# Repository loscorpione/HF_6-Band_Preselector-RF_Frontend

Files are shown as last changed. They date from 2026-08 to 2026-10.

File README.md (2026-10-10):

<h2 align="center">HF 6-Band Preselector – RF Frontend</h4>

This project is a 6-band HF RF preselector designed to improve the selectivity and dynamic performance of HF receivers, particularly homebrew and direct-conversion receivers.

<p align="center">
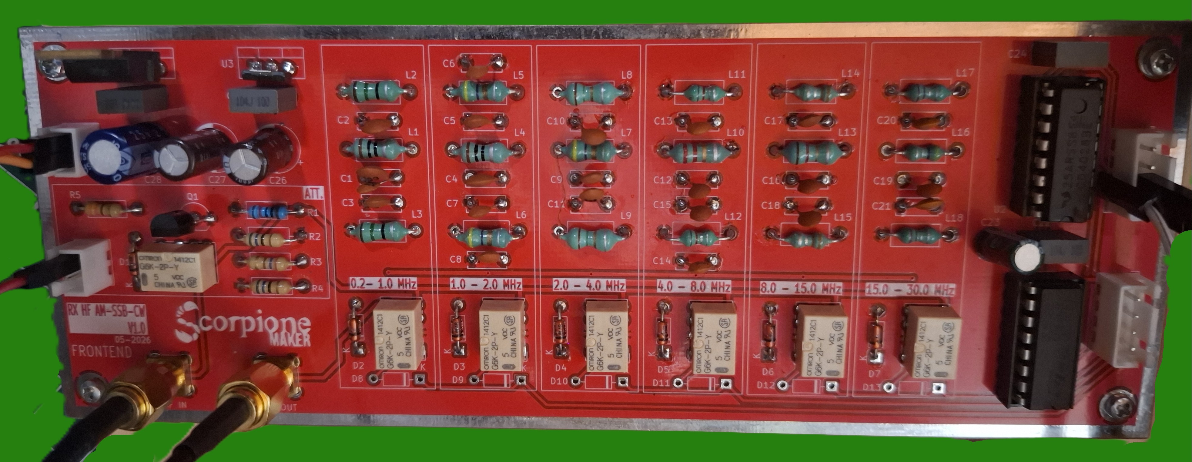
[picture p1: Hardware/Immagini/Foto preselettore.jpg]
  
</p>

The preselector covers the frequency range from 200 kHz to 30 MHz through six LC band-pass filters. The appropriate filter is selected automatically according to the band selected on the VFO.
The project was developed as an RF frontend for my ESP32 + Si5351 VFO/BFO, creating an integrated and automatically controlled RF signal chain.
In addition to the band-pass filters, the board includes a selectable 0 / -20 dB RF attenuator, controlled directly by the VFO.

<h2 align="center">🎬 Video del progetto</h2>

<p align="center">
  <a href="https://youtu.be/hL2VTXRHFpw">
    
  </a>
</p>

<h2 align="center">📻 Frequency coverage</h2>
Filter	Frequency range	Main applications
1	0.2 – 1 MHz	Long Wave, Medium Wave, 630 m
2	1 – 2 MHz	Medium Wave, 160 m
3	2 – 4 MHz	80 m, 60 m
4	4 – 8 MHz	40 m, Short Wave
5	8 – 15 MHz	30 m, 20 m, Short Wave
6	15 – 30 MHz	17 m, 15 m, 12 m, 10 m, Short Wave

<h2 align="center">🔛Filter Switching</h2>

The six filters are selected using RF relays controlled by a CD4028 decoder and an ULN2003 Darlington transistor array.
The VFO sends the selected band information to the CD4028, which activates the corresponding output. The ULN2003 then drives the relay coil, allowing the correct RF filter to be connected.
This approach reduces the number of control lines required between the VFO and the RF frontend while keeping the RF switching section simple and reliable.

## Integrazione con il VFO/BFO

- [Mappatura delle uscite digitali per la selezione dei filtri](Mappatura-Uscite-Band.md)
- [Repository VFO/BFO HF ESP32 + Si5351](https://github.com/loscorpione/VFO-BFO-HF-ESP32-Si5351)

<h2 align="center">📻 RF Attenuator</h2>

The board also includes a selectable 0 / -20 dB attenuator based on a 50 Ω resistive network.
The attenuator can be controlled directly from the VFO and can be useful when the receiver is overloaded by strong signals or out-of-band energy.

<h2 align="center">🔌 Testing</h2>

The filters were tested using a NanoVNA, measuring their frequency response, insertion loss and bandwidth.
The measured responses do not perfectly match the calculated values. The differences are most likely related to component tolerances, particularly the inductors.
Further adjustments to the filter component values are therefore planned to improve the correspondence between the calculated and measured responses.

<h2 align="center">🛠️ Hardware</h2>

The PCB was designed with particular attention to RF layout:

short RF tracks;
extensive ground plane;
physically separated filter sections;
relays positioned close to the RF paths;
50 Ω RF input and output;
dedicated filtering for each frequency range.
Status

Working prototype – further RF optimization planned.

<h2 align="center"></h2>

This repository contains the hardware design files, documentation and test information for the project.

<h2 align="center">⚠️ Disclaimer</h2>

This project is intended for educational, experimental and amateur-radio purposes.
RF circuits can behave differently depending on component tolerances, PCB construction, wiring, grounding and measurement equipment.
Always verify the circuit and its behavior before connecting it to valuable radio equipment.

<h2 align="center">📄 License</h2>

The licensing terms for this project are currently being finalized.
The original filter design is based on the work of Dian Kurniawan, which in turn references the work of Matti Hohtola (OH7SV).
Commercial use or commercial redistribution of this implementation is not authorized while the final licensing terms are being established.

ScorpioneMaker

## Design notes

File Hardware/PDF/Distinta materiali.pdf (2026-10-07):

Reference | Qty Value | Footprint | Datasheet
C1 | 1 10+2.2 nF | Capacitor_THT:C_Disc_D6.0mm_W2.5mm_P5.00mm | ~
C2 | 1 10nF | Capacitor_THT:C_Disc_D6.0mm_W2.5mm_P5.00mm | ~
C3 | 1 6.8nF | Capacitor_THT:C_Disc_D6.0mm_W2.5mm_P5.00mm | ~
C4 | 1 1nF+220pF | Capacitor_THT:C_Disc_D6.0mm_W2.5mm_P5.00mm | ~
C5,C6,C7,C8 | 4 1.5nF | Capacitor_THT:C_Disc_D6.0mm_W2.5mm_P5.00mm | ~
C9,C17,C18 | 3 680pF | Capacitor_THT:C_Disc_D6.0mm_W2.5mm_P5.00mm | ~
C10,C11 | 2 2nF | Capacitor_THT:C_Disc_D6.0mm_W2.5mm_P5.00mm | ~
C12,C15,C16 | 3 180pF | Capacitor_THT:C_Disc_D6.0mm_W2.5mm_P5.00mm | ~
C13,C14 | 2 1nF | Capacitor_THT:C_Disc_D6.0mm_W2.5mm_P5.00mm | ~
C19 | 1 120pF | Capacitor_THT:C_Disc_D6.0mm_W2.5mm_P5.00mm | ~
C20,C21 | 2 270pF | Capacitor_THT:C_Disc_D6.0mm_W2.5mm_P5.00mm | ~
C22,C24,C25,C29 | 4 100nF | Capacitor_THT:C_Rect_L7.0mm_W2.5mm_P5.00mm | ~
C23 | 1 10uF16V | Capacitor_THT:CP_Radial_D4.0mm_P2.00mm | ~
C26 | 1 100uF 25V | Capacitor_THT:CP_Radial_D7.5mm_P2.50mm | ~
C27,C28 | 2 100uF25V | Capacitor_THT:CP_Radial_D7.5mm_P2.50mm | ~
D1,D2,D3,D4,D5,D6,D7,D8,D9,D10,
D11,D12,D13 | 13 1N4148 | Diode_THT:D_DO-35_SOD27_P7.62mm_Horizontal | https://assets.nexperia.com/documents/data-sheet/1N4148_1N4448.pdf
H1,H2,H3,H4 | 4 MountingHole_PadMountingHole:MountingHole_3.2mm_M3_DIN965_Pad | ~
J1 | 1 RF OUT | Connector_Coaxial:SMA_Amphenol_901-144_Vertical | ~
J2 | 1 RF IN | Connector_Coaxial:SMA_Amphenol_901-144_Vertical | ~
J3 | 1 +12V | Connector_JST:JST_XH_B2B-XH-A_1x02_P2.50mm_Vertical | ~
J4 | 1 Band | Connector_JST:JST_XH_B4B-XH-A_1x04_P2.50mm_Vertical | ~
J5 | 1 Att. | Connector_JST:JST_XH_B2B-XH-A_1x02_P2.50mm_Vertical | ~
J6 | 1 PBF VFO | Connector_JST:JST_XH_B4B-XH-A_1x04_P2.50mm_Vertical | ~
K1,K2,K3,K4,K5,K6,K7 | 7 G6K-2 | Relay_THT:Relay_DPDT_Omron_G6K-2P-Y | http://omronfs.omron.com/en_US/ecb/products/pdf/en-g6k.pdf
L1,L4 | 2 10uH | Inductor_THT:L_Axial_L7.0mm_D3.3mm_P10.16mm_Horizontal_Fastron_MICC ~
L2,L3 | 2 15uH | Inductor_THT:L_Axial_L7.0mm_D3.3mm_P10.16mm_Horizontal_Fastron_MICC ~
L5,L6,L7 | 3 4.7uH | Inductor_THT:L_Axial_L7.0mm_D3.3mm_P10.16mm_Horizontal_Fastron_MICC ~
L8,L9 | 2 1.5uH | Inductor_THT:L_Axial_L7.0mm_D3.3mm_P10.16mm_Horizontal_Fastron_MICC ~
L10 | 1 2.2uH | Inductor_THT:L_Axial_L7.0mm_D3.3mm_P10.16mm_Horizontal_Fastron_MICC ~
L11,L12 | 2 820nH | Inductor_THT:L_Axial_L7.0mm_D3.3mm_P10.16mm_Horizontal_Fastron_MICC ~
L13 | 1 1.2u | Inductor_THT:L_Axial_L7.0mm_D3.3mm_P10.16mm_Horizontal_Fastron_MICC ~
L14,L15 | 2 330nH | Inductor_THT:L_Axial_L7.0mm_D3.3mm_P10.16mm_Horizontal_Fastron_MICC ~
L16 | 1 470nH | Inductor_THT:L_Axial_L7.0mm_D3.3mm_P10.16mm_Horizontal_Fastron_MICC ~
L17,L18 | 2 220nH | Inductor_THT:L_Axial_L7.0mm_D3.3mm_P10.16mm_Horizontal_Fastron_MICC ~
Q1 | 1 BC547 | Package_TO_SOT_THT:TO-92_Inline_Wide | https://www.onsemi.com/pub/Collateral/BC550-D.pdf
R1 | 1 10k | Resistor_THT:R_Axial_DIN0207_L6.3mm_D2.5mm_P10.16mm_Horizontal~
R2,R4 | 2 56 | Resistor_THT:R_Axial_DIN0207_L6.3mm_D2.5mm_P10.16mm_Horizontal~
R3 | 1 270 | Resistor_THT:R_Axial_DIN0207_L6.3mm_D2.5mm_P10.16mm_Horizontal~
R5 | 1 1K | Resistor_THT:R_Axial_DIN0207_L6.3mm_D2.5mm_P10.16mm_Horizontal~
U1 | 1 ULN2003 | Package_DIP:DIP-16_W7.62mm | http://www.ti.com/lit/ds/symlink/uln2003a.pdf
U2 | 1 4028 | Package_DIP:DIP-16_W7.62mm | http://www.intersil.com/content/dam/Intersil/documents/cd40/cd4028bms.pdf
U3 | 1 LM1117T-3.3 | Package_TO_SOT_THT:TO-220-3_Vertical | http://www.ti.com/lit/ds/symlink/lm1117.pdf
U4 | 1 LM7805_TO220 | Package_TO_SOT_THT:TO-220-3_Vertical | https://www.onsemi.cn/PowerSolutions/document/MC7800-D.PDF

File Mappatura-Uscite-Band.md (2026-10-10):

# Configurazione delle uscite digitali per la selezione dei filtri

## Introduzione

Se si utilizza il preselettore **HF 6-Band Preselector RF Frontend** insieme al progetto [VFO/BFO HF ESP32 + Si5351](https://github.com/loscorpione/VFO-BFO-HF-ESP32-Si5351), è necessario configurare la mappatura delle uscite digitali in funzione della frequenza selezionata sul VFO.

Il firmware del VFO deve generare il codice binario corrispondente alla banda di frequenza utilizzata, in modo da comandare il circuito di selezione dei filtri del preselettore.

## Dove modificare il firmware

La configurazione si trova nel file `DigiOUT.cpp`, all'interno della funzione:

```cpp
void updateModeOutputs()
```

In questa funzione viene verificato il valore di `displayedFrequency` e vengono impostate le uscite digitali in base alla banda di frequenza selezionata.

Per ogni filtro vengono definiti un limite inferiore e un limite superiore. Quando la frequenza rientra nell'intervallo specificato, alla variabile `outputState` viene assegnato il codice binario corrispondente.

**Attenzione:** gli intervalli di frequenza riportati nel codice devono corrispondere alle bande effettive dei filtri installati nel preselettore.

## Tabella di selezione dei filtri

La configurazione di esempio prevede sei filtri passa-banda e una condizione aggiuntiva per le frequenze fuori banda.

| Frequenza selezionata | Codice binario | Banda |
|---|---|---|
| 200 kHz – 1 MHz | `000` | Filtro 1 |
| 1 – 2 MHz | `001` | Filtro 2 |
| 2 – 4 MHz | `010` | Filtro 3 |
| 4 – 8 MHz | `011` | Filtro 4 |
| 8 – 15 MHz | `100` | Filtro 5 |
| 15 – 30 MHz | `101` | Filtro 6 |
| Fuori banda | `110` | Nessun filtro attivo |

I codici binari sono quelli impostati nel firmware e devono essere compatibili con il circuito digitale di decodifica del preselettore.

## Esempio di configurazione nel codice

Il seguente frammento mostra come vengono associate le frequenze ai codici binari:

```cpp
void updateModeOutputs() {
    uint8_t outputState = 0;

    // ====================================================
    // Mappatura: Selezione filtri passa banda Preselettore
    // ====================================================
    if (displayedFrequency >= 200000 &&
        displayedFrequency < 1000000) {
        outputState = 0b000;   // da 200kHz a 1000kHz - Band=000 
    }
    else if (displayedFrequency >= 1000000 &&
             displayedFrequency < 2000000) {
        outputState = 0b001; // 1000kHz a 2000kHz - Band=001
    }
    else if (displayedFrequency >= 2000000 &&
             displayedFrequency < 4000000) {
        outputState = 0b010; // 2000kHz a 4000kHz - Band=010 
    }
    else if (displayedFrequency >= 4000000 &&
             displayedFrequency < 8000000) {
        outputState = 0b011; // 4000kHz a 8000kHz - Band=011
    }
    else if (displayedFrequency >= 8000000 &&
             displayedFrequency < 15000000) {
        outputState = 0b100; // 8000kHz a 15MHz - Band=100
    }
    else if (displayedFrequency >= 15000000 &&
             displayedFrequency <= 30000000) {
        outputState = 0b101;  // 15MHz a 30MHz - Band=101
    }
    else {
        outputState = 0b110;  // Fuori banda - band=110 (nessun filtro attivo)
    }

    // La gestione delle uscite digitali prosegue qui.
}
```

*Nota: questo è un esempio della logica di mappatura. Per mantenere il funzionamento del firmware originale, conservare anche le istruzioni successive della funzione che trasferiscono `outputState` alle uscite fisiche.*

## Come personalizzare la mappatura

Se si utilizzano filtri con intervalli di frequenza differenti, è possibile modificare i limiti delle condizioni `if` e `else if`.

Per ogni filtro occorre:

1. Impostare la frequenza minima di attivazione.
2. Impostare la frequenza massima di attivazione.
3. Assegnare il codice binario previsto dal circuito di decodifica.
4. Verificare che gli intervalli non si sovrappongano e che non rimangano intervalli indesiderati.
5. Verificare il corretto funzionamento delle uscite digitali e dei relè.

Gli estremi degli intervalli devono essere scelti con attenzione per evitare ambiguità nei punti di passaggio tra una banda e la successiva.

## Verifica del funzionamento

Dopo aver modificato e caricato il firmware:

- Selezionare frequenze appartenenti a ciascuna delle sei bande.
- Verificare che il codice binario generato sia quello previsto.
- Controllare che venga attivato il filtro corrispondente.
- Provare anche frequenze inferiori a 200 kHz e superiori a 30 MHz per verificare la condizione fuori banda.

Per maggiori informazioni sul circuito RF e sul relativo sistema di selezione, consultare il [repository HF 6-Band Preselector RF Frontend](https://github.com/loscorpione/HF-6-Band_Preselector-RF_Frontend).

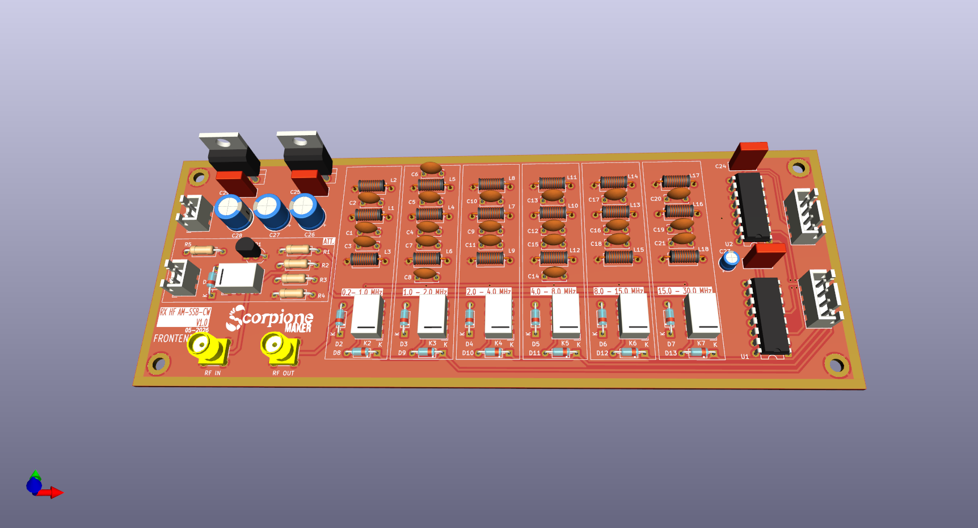
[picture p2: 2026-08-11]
Hardware/Immagini/6x-BPF-FRONTEND.png

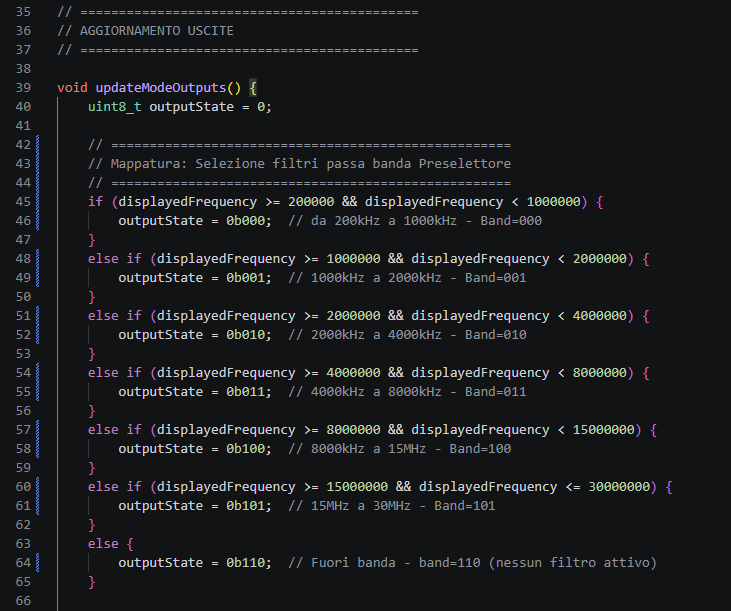
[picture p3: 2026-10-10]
Immage/Mappatura-uscite-band.png

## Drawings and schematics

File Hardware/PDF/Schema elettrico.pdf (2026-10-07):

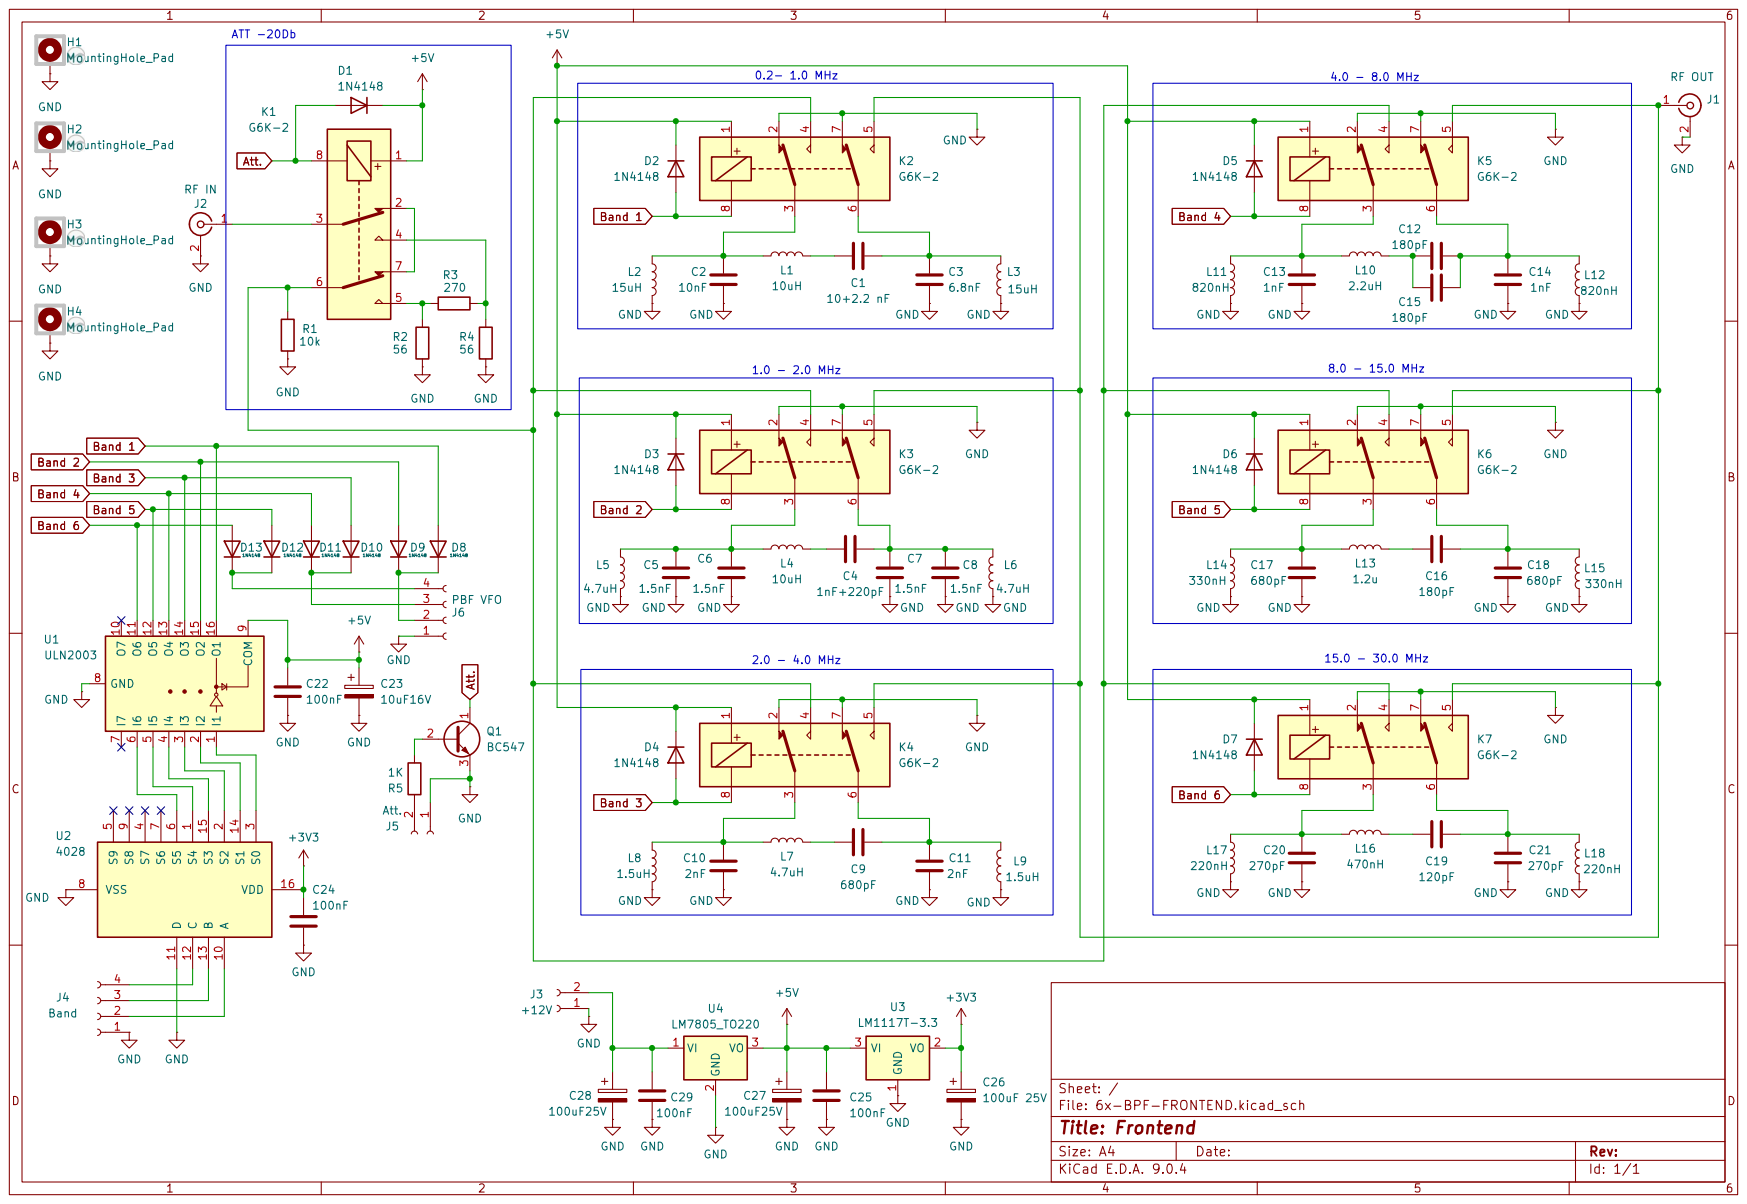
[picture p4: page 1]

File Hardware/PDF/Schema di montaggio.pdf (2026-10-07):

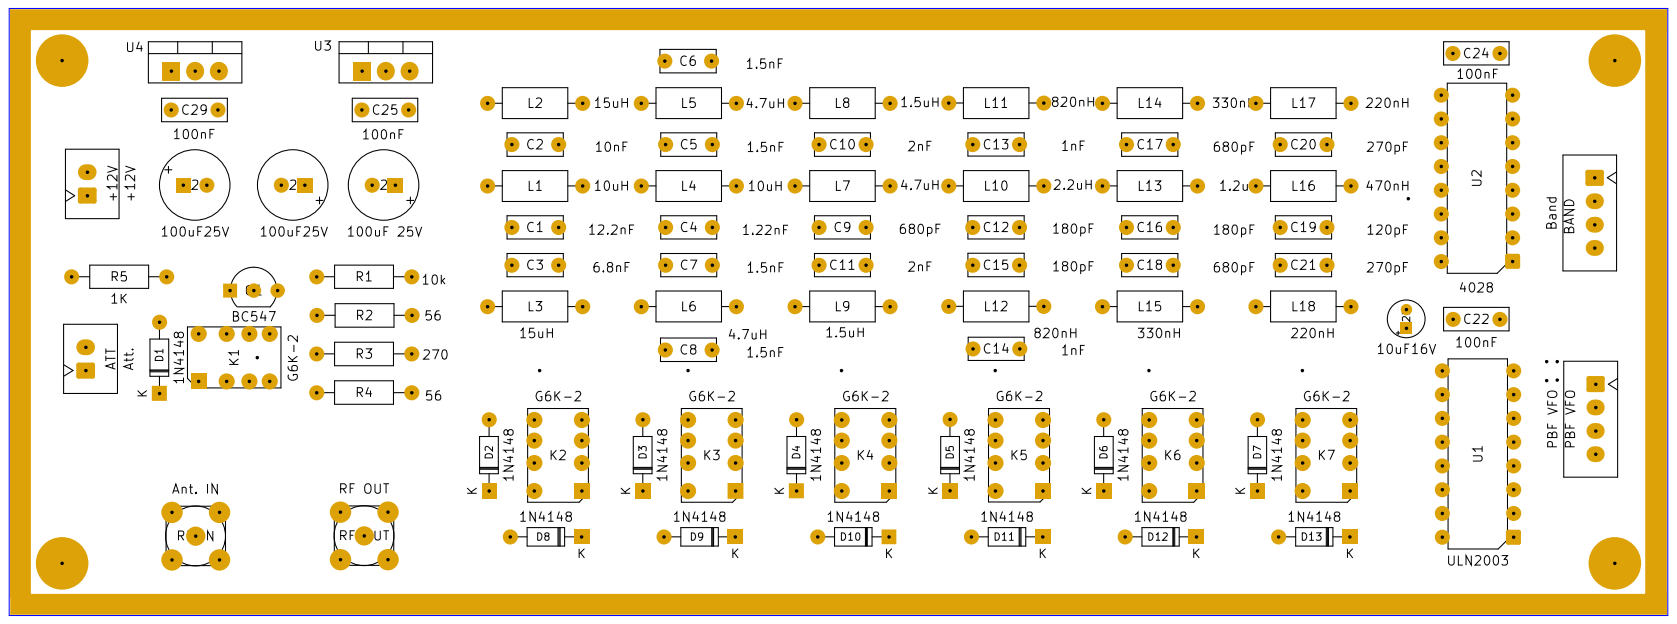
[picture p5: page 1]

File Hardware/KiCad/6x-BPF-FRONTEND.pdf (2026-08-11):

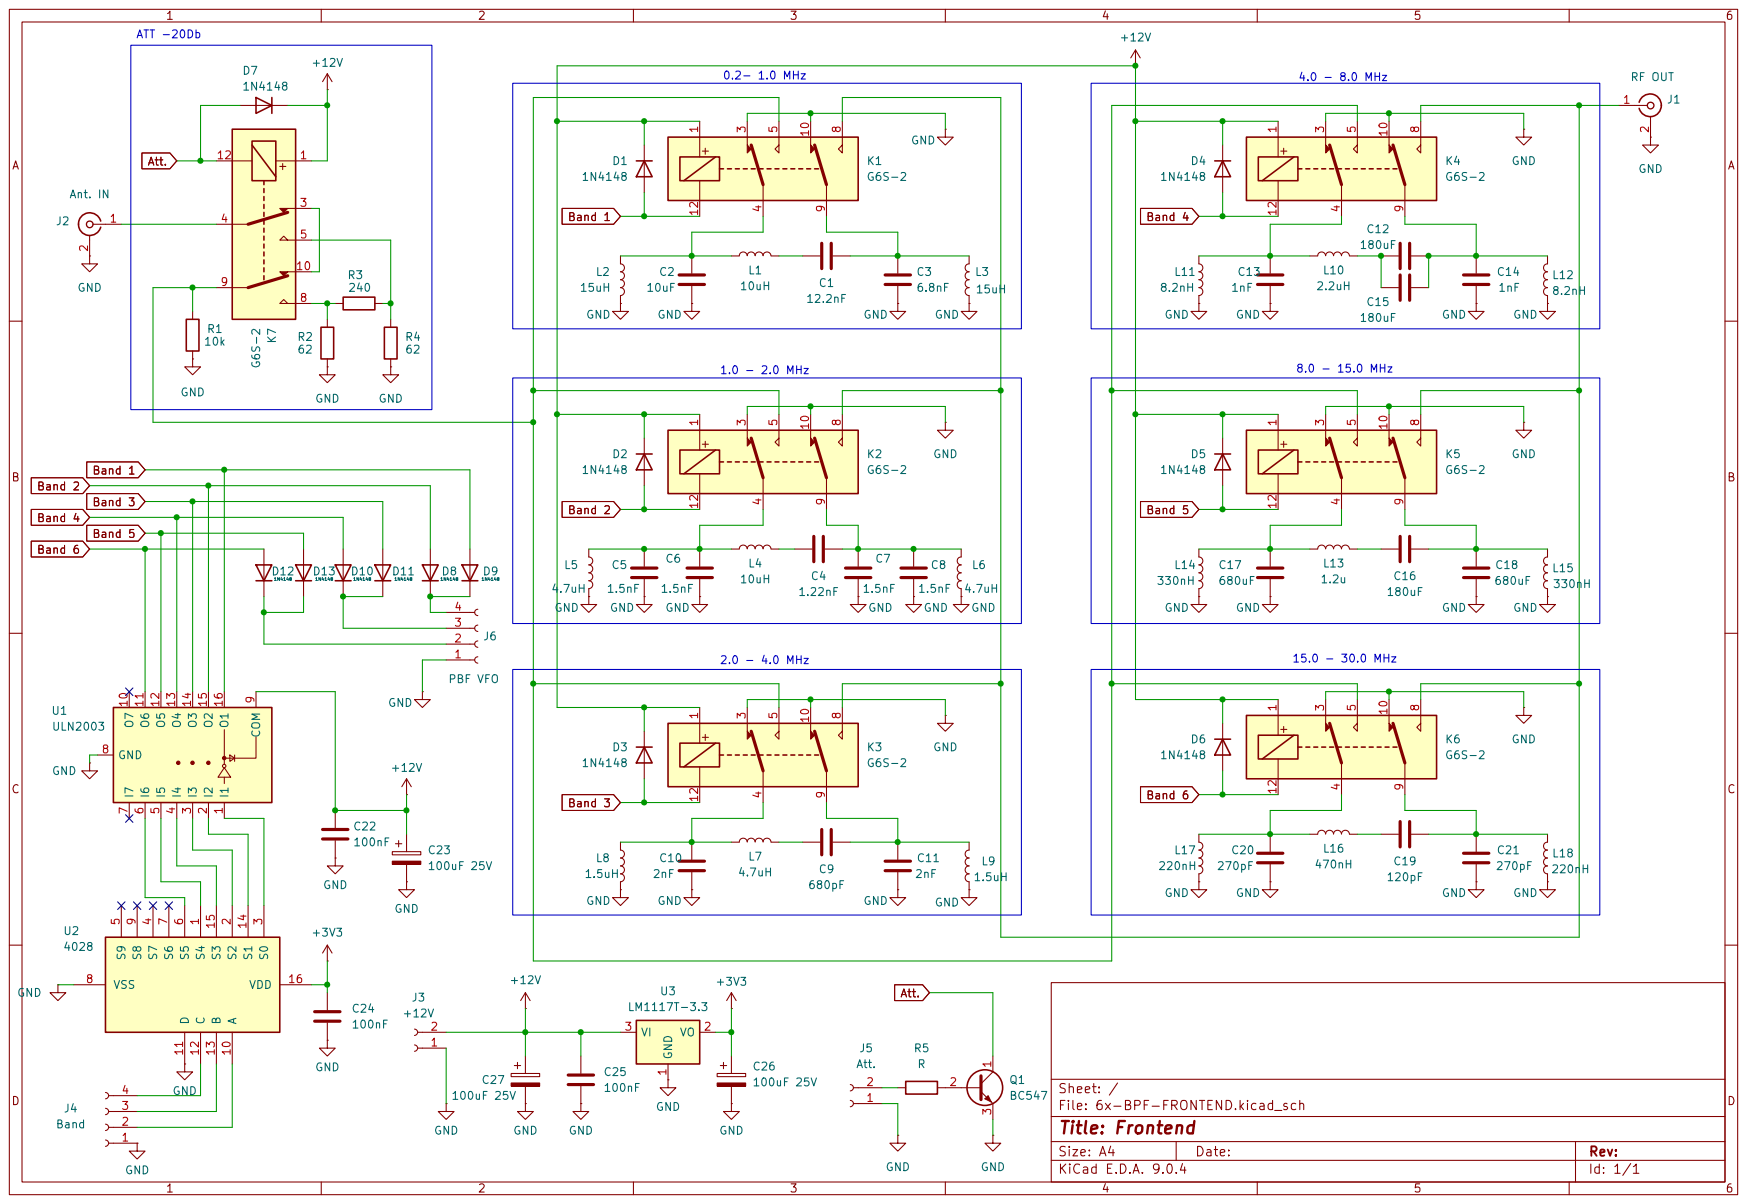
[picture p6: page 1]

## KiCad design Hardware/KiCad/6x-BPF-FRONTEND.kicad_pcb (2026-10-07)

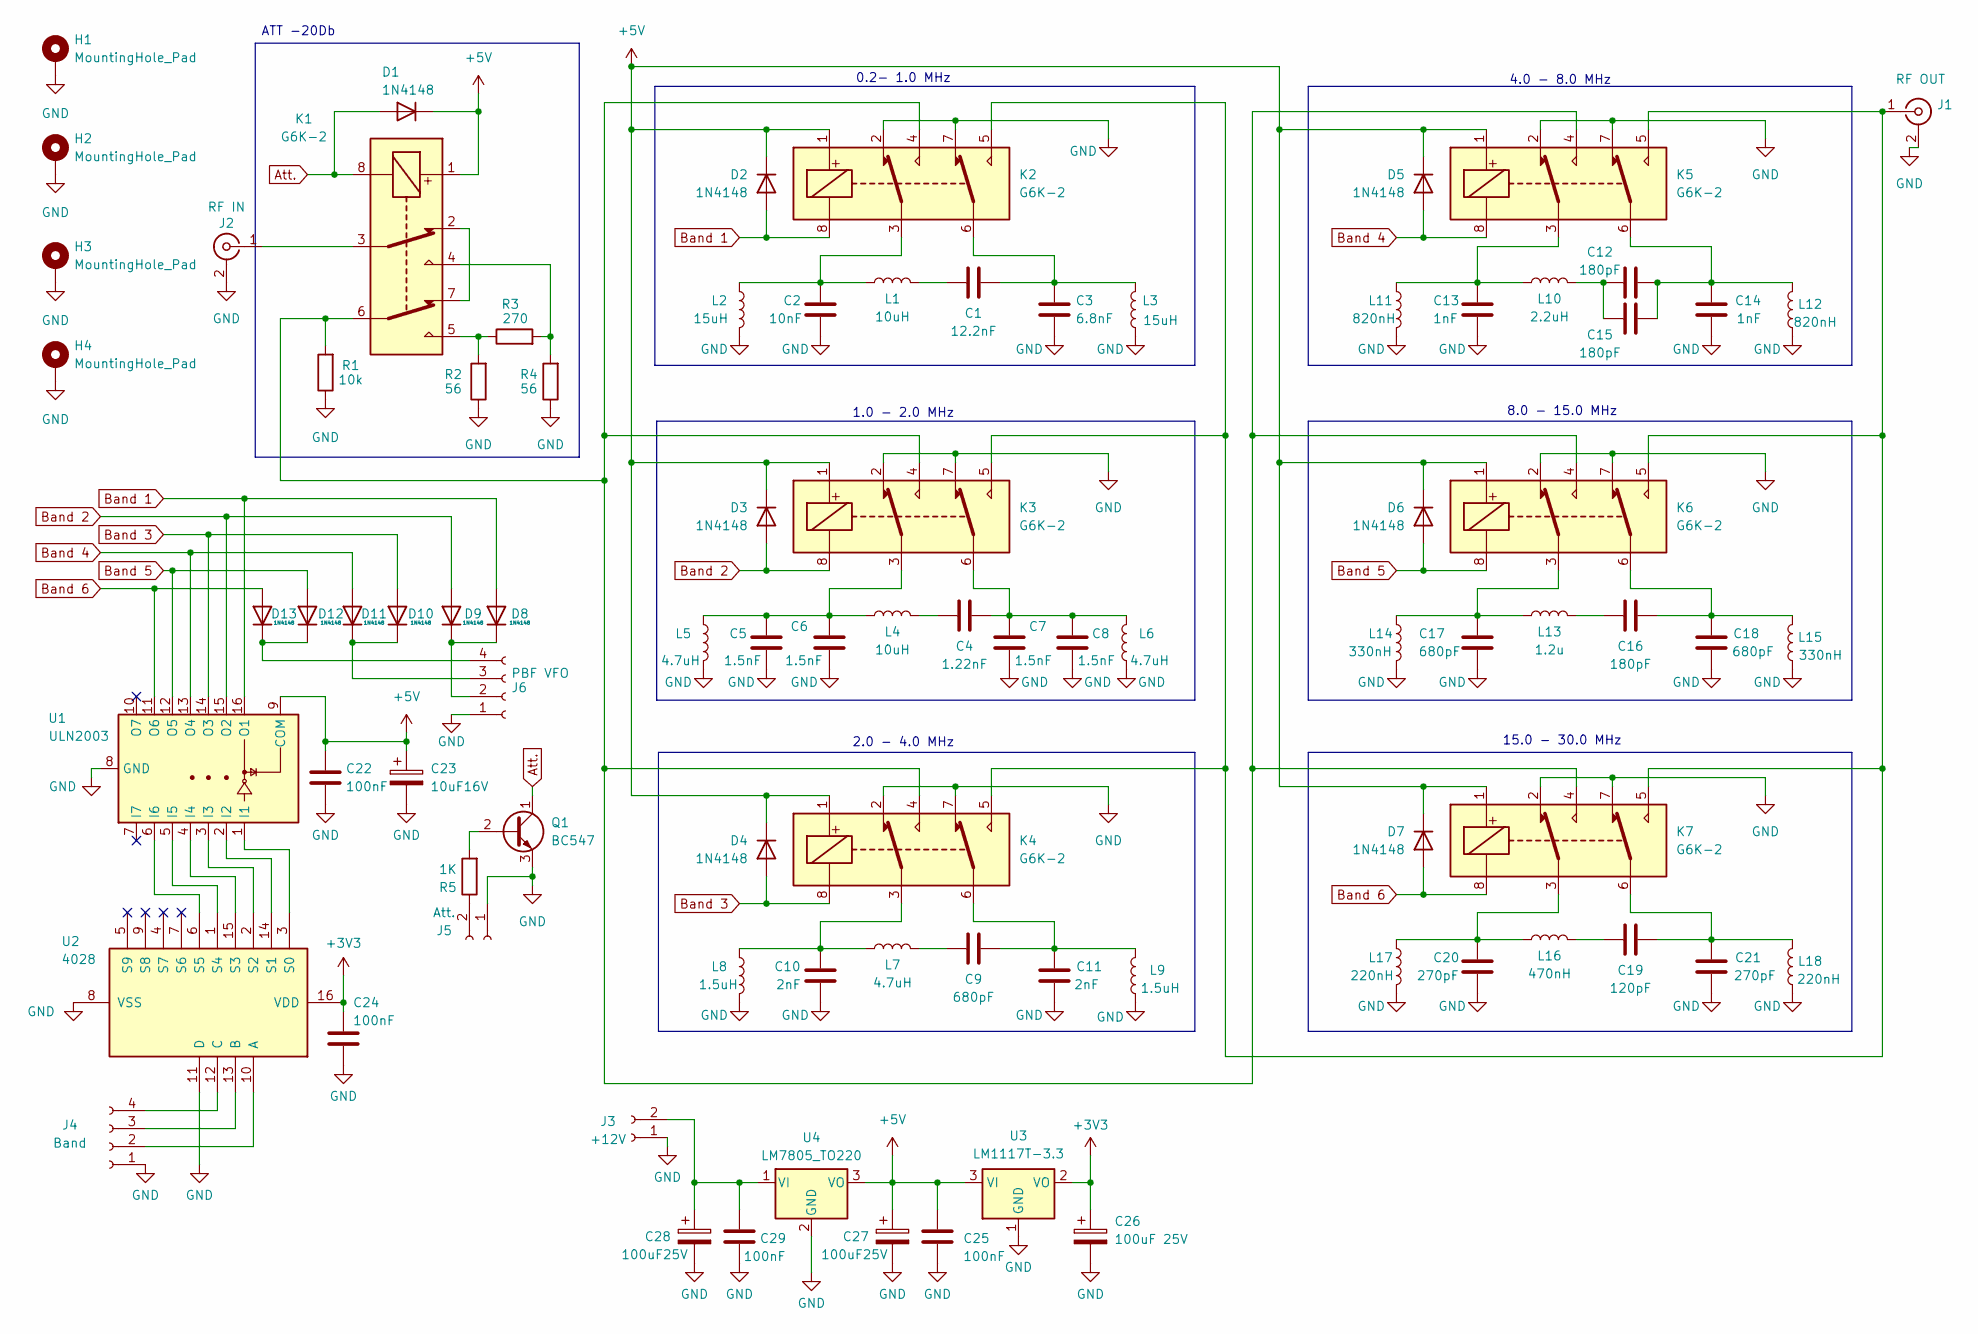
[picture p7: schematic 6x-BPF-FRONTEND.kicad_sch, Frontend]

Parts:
C1: 12.2nF; C_Disc_D6.0mm_W2.5mm_P5.00mm
C2: 10nF; C_Disc_D6.0mm_W2.5mm_P5.00mm
C3: 6.8nF; C_Disc_D6.0mm_W2.5mm_P5.00mm
C4: 1.22nF; C_Disc_D6.0mm_W2.5mm_P5.00mm
C5, C6, C7, C8: 1.5nF; C_Disc_D6.0mm_W2.5mm_P5.00mm
C9, C17, C18: 680pF; C_Disc_D6.0mm_W2.5mm_P5.00mm
C10, C11: 2nF; C_Disc_D6.0mm_W2.5mm_P5.00mm
C12, C15, C16: 180pF; C_Disc_D6.0mm_W2.5mm_P5.00mm
C13, C14: 1nF; C_Disc_D6.0mm_W2.5mm_P5.00mm
C19: 120pF; C_Disc_D6.0mm_W2.5mm_P5.00mm
C20, C21: 270pF; C_Disc_D6.0mm_W2.5mm_P5.00mm
C22, C24, C25, C29: 100nF; C_Rect_L7.0mm_W2.5mm_P5.00mm
C23: 10uF16V; CP_Radial_D4.0mm_P2.00mm
C26: 100uF 25V; CP_Radial_D7.5mm_P2.50mm
C27, C28: 100uF25V; CP_Radial_D7.5mm_P2.50mm
D1, D2, D3, D4, D5, D6, D7, D8, D9, D10, D11, D12, D13: 1N4148; D_DO-35_SOD27_P7.62mm_Horizontal
H1, H2, H3, H4: MountingHole_Pad; MountingHole_3.2mm_M3_DIN965_Pad
J1: RF OUT; SMA_Amphenol_901-144_Vertical
J2: RF IN; SMA_Amphenol_901-144_Vertical
J3: +12V; JST_XH_B2B-XH-A_1x02_P2.50mm_Vertical
J4: Band; JST_XH_B4B-XH-A_1x04_P2.50mm_Vertical
J5: Att.; JST_XH_B2B-XH-A_1x02_P2.50mm_Vertical
J6: PBF VFO; JST_XH_B4B-XH-A_1x04_P2.50mm_Vertical
K1, K2, K3, K4, K5, K6, K7: G6K-2; Relay_DPDT_Omron_G6K-2P-Y
L1, L4: 10uH; L_Axial_L7.0mm_D3.3mm_P10.16mm_Horizontal_Fastron_MICC
L2, L3: 15uH; L_Axial_L7.0mm_D3.3mm_P10.16mm_Horizontal_Fastron_MICC
L5, L6, L7: 4.7uH; L_Axial_L7.0mm_D3.3mm_P10.16mm_Horizontal_Fastron_MICC
L8, L9: 1.5uH; L_Axial_L7.0mm_D3.3mm_P10.16mm_Horizontal_Fastron_MICC
L10: 2.2uH; L_Axial_L7.0mm_D3.3mm_P10.16mm_Horizontal_Fastron_MICC
L11, L12: 820nH; L_Axial_L7.0mm_D3.3mm_P10.16mm_Horizontal_Fastron_MICC
L13: 1.2u; L_Axial_L7.0mm_D3.3mm_P10.16mm_Horizontal_Fastron_MICC
L14, L15: 330nH; L_Axial_L7.0mm_D3.3mm_P10.16mm_Horizontal_Fastron_MICC
L16: 470nH; L_Axial_L7.0mm_D3.3mm_P10.16mm_Horizontal_Fastron_MICC
L17, L18: 220nH; L_Axial_L7.0mm_D3.3mm_P10.16mm_Horizontal_Fastron_MICC
Q1: BC547; TO-92_Inline_Wide
R1: 10k; R_Axial_DIN0207_L6.3mm_D2.5mm_P10.16mm_Horizontal
R2, R4: 56; R_Axial_DIN0207_L6.3mm_D2.5mm_P10.16mm_Horizontal
R3: 270; R_Axial_DIN0207_L6.3mm_D2.5mm_P10.16mm_Horizontal
R5: 1K; R_Axial_DIN0207_L6.3mm_D2.5mm_P10.16mm_Horizontal
U1: ULN2003; DIP-16_W7.62mm
U2: 4028; DIP-16_W7.62mm
U3: LM1117T-3.3; TO-220-3_Vertical
U4: LM7805_TO220; TO-220-3_Vertical

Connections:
+3V3: C24.1, C26.1, U2.16 (VDD), U3.2 (VO)
+5V: C22.1, C23.1, C25.1, C27.1, D1.1 (K), D2.1 (K), D3.1 (K), D4.1 (K), D5.1 (K), D6.1 (K), D7.1 (K), K1.1, K2.1, K3.1, K4.1, K5.1, K6.1, K7.1, U1.9 (COM), U3.3 (VI), U4.3 (VO)
Att.: D1.2 (A), K1.8, Q1.1 (C)
Band 1: D2.2 (A), D8.2 (A), K2.8, U1.16 (O1)
Band 2: D3.2 (A), D9.2 (A), K3.8, U1.15 (O2)
Band 3: D4.2 (A), D10.2 (A), K4.8, U1.14 (O3)
Band 4: D5.2 (A), D11.2 (A), K5.8, U1.13 (O4)
Band 5: D6.2 (A), D12.2 (A), K6.8, U1.12 (O5)
Band 6: D7.2 (A), D13.2 (A), K7.8, U1.11 (O6)
GND: C2.2, C3.2, C5.2, C6.2, C7.2, C8.2, C10.2, C11.2, C13.2, C14.2, C17.2, C18.2, C20.2, C21.2, C22.2, C23.2, C24.2, C25.2, C26.2, C27.2, C28.2, C29.2, H1.1, H2.1, H3.1, H4.1, J1.2 (Ext), J2.2 (Ext), J3.1, J4.1, J5.1, J6.1, K2.2, K2.7, K3.2, K3.7, K4.2, K4.7, K5.2, K5.7, K6.2, K6.7, K7.2, K7.7, L2.2, L3.2, L5.2, L6.2, L8.2, L9.2, L11.2, L12.2, L14.2, L15.2, L17.2, L18.2, Q1.3 (E), R1.1, R2.1, R4.1, U1.8 (GND), U2.8 (VSS), U2.11 (D), U3.1 (GND), U4.2 (GND); also elsewhere on the board
unnamed: C1.1, C3.1, K2.6, L3.1
unnamed: C1.2, L1.2
unnamed: C2.1, K2.3, L1.1, L2.1
unnamed: C4.1, C7.1, C8.1, K3.6, L6.1
unnamed: C4.2, L4.2
unnamed: C5.1, C6.1, K3.3, L4.1, L5.1
unnamed: C9.2, L7.2
unnamed: C10.1, K4.3, L7.1, L8.1
unnamed: C9.1, C11.1, K4.6, L9.1
unnamed: C12.1, C14.1, C15.1, K5.6, L12.1
unnamed: C12.2, C15.2, L10.2
unnamed: C13.1, K5.3, L10.1, L11.1
unnamed: C16.1, C18.1, K6.6, L15.1
unnamed: C16.2, L13.2
unnamed: C17.1, K6.3, L13.1, L14.1
unnamed: C19.1, C21.1, K7.6, L18.1
unnamed: C19.2, L16.2
unnamed: C20.1, K7.3, L16.1, L17.1
unnamed 28: D8.1 (K), D9.1 (K), J6.2; also elsewhere on the board
unnamed 29: D10.1 (K), D11.1 (K), J6.3; also elsewhere on the board
unnamed 30: D12.1 (K), D13.1 (K), J6.4; also elsewhere on the board
unnamed 31: J1.1 (In), K2.5, K3.5, K4.5, K5.5, K6.5, K7.5; also elsewhere on the board
unnamed 32: J2.1 (In), K1.3; also elsewhere on the board
unnamed 33: C28.1, C29.1, J3.2, U4.1 (VI); also elsewhere on the board
unnamed 34: J4.2, U2.10 (A); also elsewhere on the board
unnamed 35: J4.3, U2.13 (B); also elsewhere on the board
unnamed 36: J4.4, U2.12 (C); also elsewhere on the board
unnamed 37: J5.2, R5.1; also elsewhere on the board
unnamed: K1.2, K1.7
unnamed: K1.4, R3.2, R4.2
unnamed: K1.5, R2.2, R3.1
unnamed: K1.6, K2.4, K3.4, K4.4, K5.4, K6.4, K7.4, R1.2
unnamed: Q1.2 (B), R5.2
unnamed: U1.1 (I1), U2.3 (S0)
unnamed: U1.2 (I2), U2.14 (S1)
unnamed: U1.3 (I3), U2.2 (S2)
unnamed: U1.4 (I4), U2.15 (S3)
unnamed: U1.5 (I5), U2.1 (S4)
unnamed: U1.6 (I6), U2.6 (S5)

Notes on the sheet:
2.0 - 4.0 MHz
1.0 - 2.0 MHz
8.0 - 15.0 MHz
0.2- 1.0 MHz
4.0 - 8.0 MHz
ATT -20Db
15.0 - 30.0 MHz

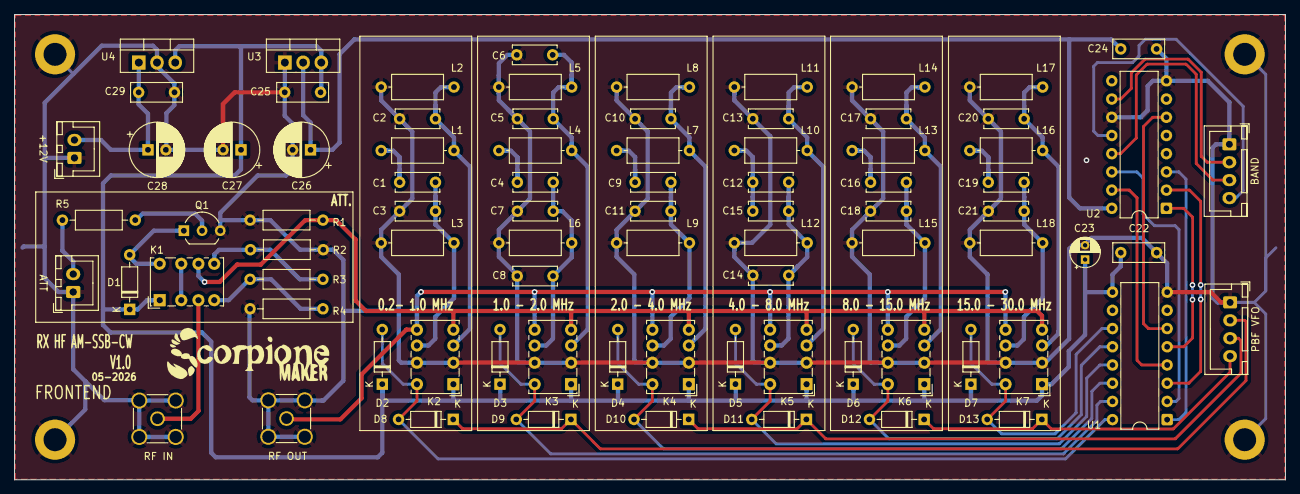
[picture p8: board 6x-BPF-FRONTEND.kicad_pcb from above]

Board: 2 copper layers, 177.3 x 64.9 mm, 87 parts (0 on the bottom side), 49 nets.

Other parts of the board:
+12V: +12V; JST_XH_B2B-XH-A_1x02_P2.50mm_Vertical
ATT: Att.; JST_XH_B2B-XH-A_1x02_P2.50mm_Vertical
BAND : Band; JST_XH_B4B-XH-A_1x04_P2.50mm_Vertical
PBF VFO: PBF VFO; JST_XH_B4B-XH-A_1x04_P2.50mm_Vertical
RF IN: Ant. IN; SMA_Amphenol_901-144_Vertical
RF OUT: RF OUT; SMA_Amphenol_901-144_Vertical

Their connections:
GND: +12V.1, ATT.1, BAND.1, PBF VFO.1, RF IN.2 (Ext), RF OUT.2 (Ext); also elsewhere on the board
unnamed 28: PBF VFO.2; also elsewhere on the board
unnamed 29: PBF VFO.3; also elsewhere on the board
unnamed 30: PBF VFO.4; also elsewhere on the board
unnamed 31: RF OUT.1 (In); also elsewhere on the board
unnamed 32: RF IN.1 (In); also elsewhere on the board
unnamed 33: +12V.2; also elsewhere on the board
unnamed 34: BAND.2; also elsewhere on the board
unnamed 35: BAND.3; also elsewhere on the board
unnamed 36: BAND.4; also elsewhere on the board
unnamed 37: ATT.2; also elsewhere on the board

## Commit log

2026-08-11 Revise README with detailed project information
    Expanded project description and added details about frequency coverage, filter switching, RF attenuator, testing, hardware design, and project status.
2026-08-11 aggiunto file Kicad e gerber
    [6x-BPF-FRONTEND-B_Cu.gbr, 6x-BPF-FRONTEND-B_Mask.gbr, 6x-BPF-FRONTEND-B_Paste.gbr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]
2026-08-11 upload file PDF
    [6x-BPF-FRONTEND.csv]
2026-10-07 Correzione bug
    Corretto alcuni valori che nello schema erano errati
    [6x-BPF-FRONTEND.csv, 6x-BPF-FRONTEND.kicad_pcb, 6x-BPF-FRONTEND.kicad_sch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]
2026-10-07 Aggiornato distinta materiali
    [6x-BPF-FRONTEND.csv, 6x-BPF-FRONTEND.kicad_sch, Distinta materiali.xlsx]
2026-10-10 inserito dettagli mappatura Filtri nel VFO
    Istruzioni per la mappatura dei filtri per chi usa il mio VFO/BFO
2026-10-10 Revise filter table headers and numbering
    Updated filter table to use 'Banda di Frequenza' and corrected filter numbering.
